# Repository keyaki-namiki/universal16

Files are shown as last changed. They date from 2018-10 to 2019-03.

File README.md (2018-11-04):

## universal16

4x4 simple Key-matrix (and some functions) with universal board

### feature(s)

- No wire is there between matrix(es) and controller footprint (for trying new controller such as Arduino, Mbed, PIC,and so on...)
- Matrix circuit is been dragged out to pads for hand-wiring
- Jumper pads for making 'hand-wiring' easier
- The universal board part for making your function (rotary encoder, potentiometer, joystick module, etc...)
- You can use universal board part in both left-side and right-side

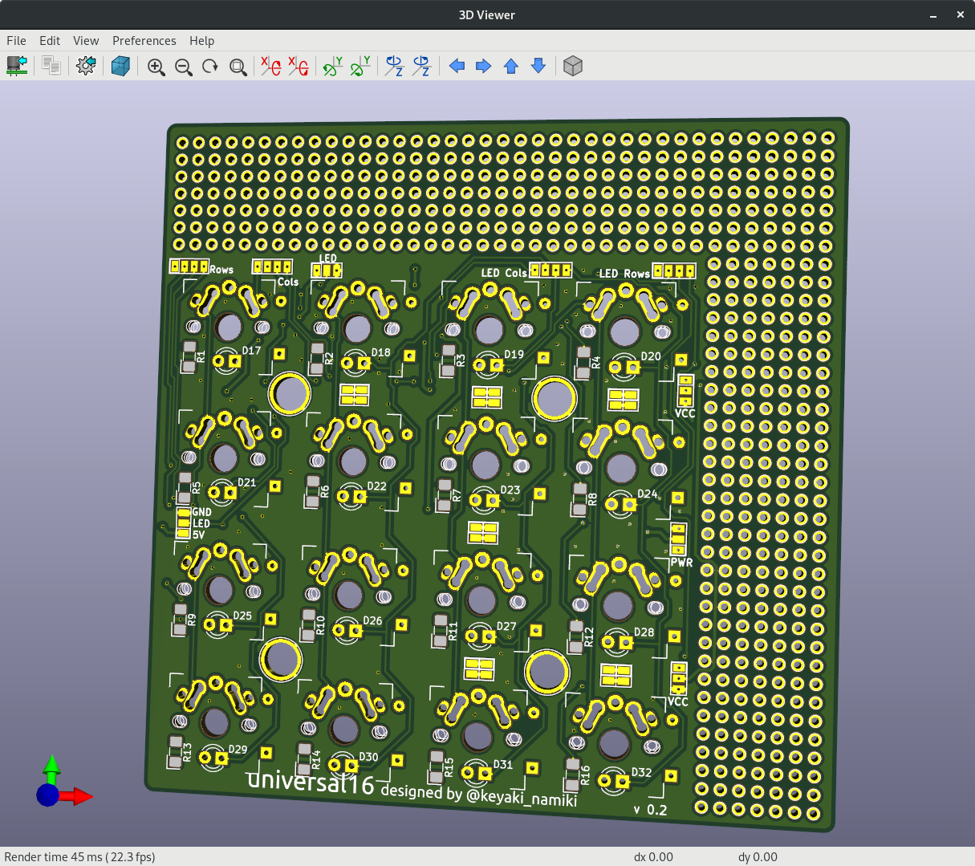
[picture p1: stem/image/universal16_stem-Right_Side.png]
universal16-stem_image_1


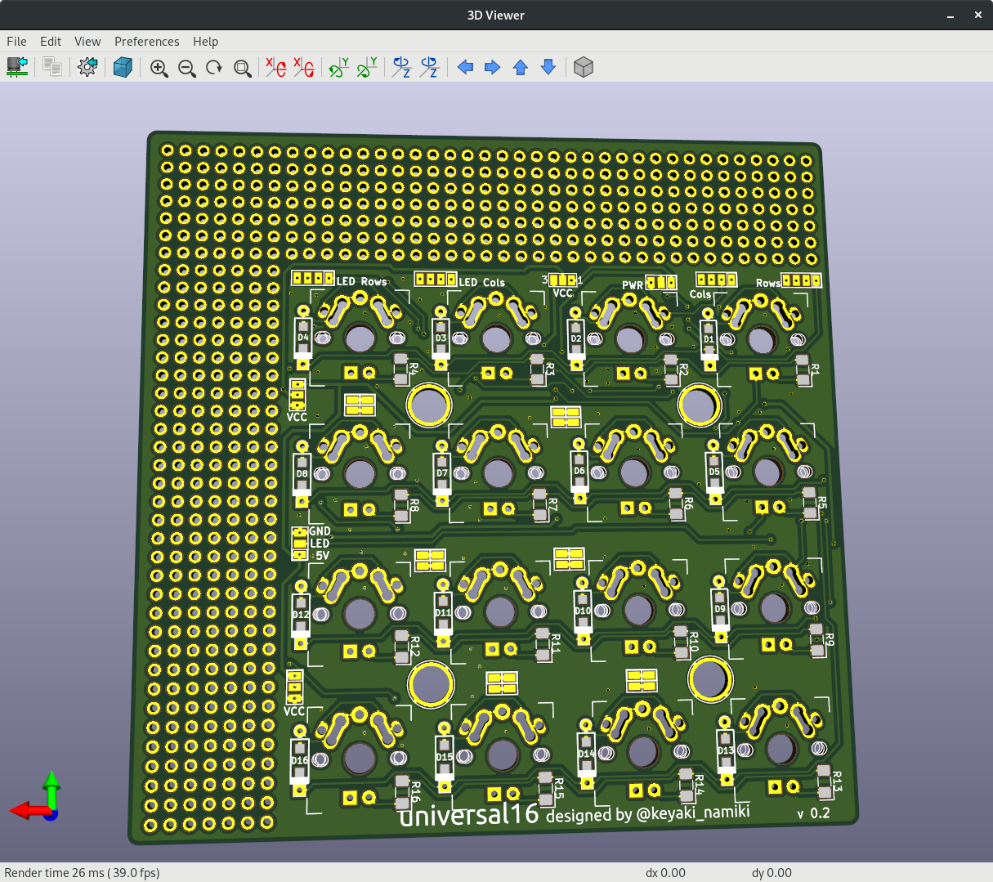
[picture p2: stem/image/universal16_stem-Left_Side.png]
universal16-stem_image_2


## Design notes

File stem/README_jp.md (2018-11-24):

## universal16 Stem

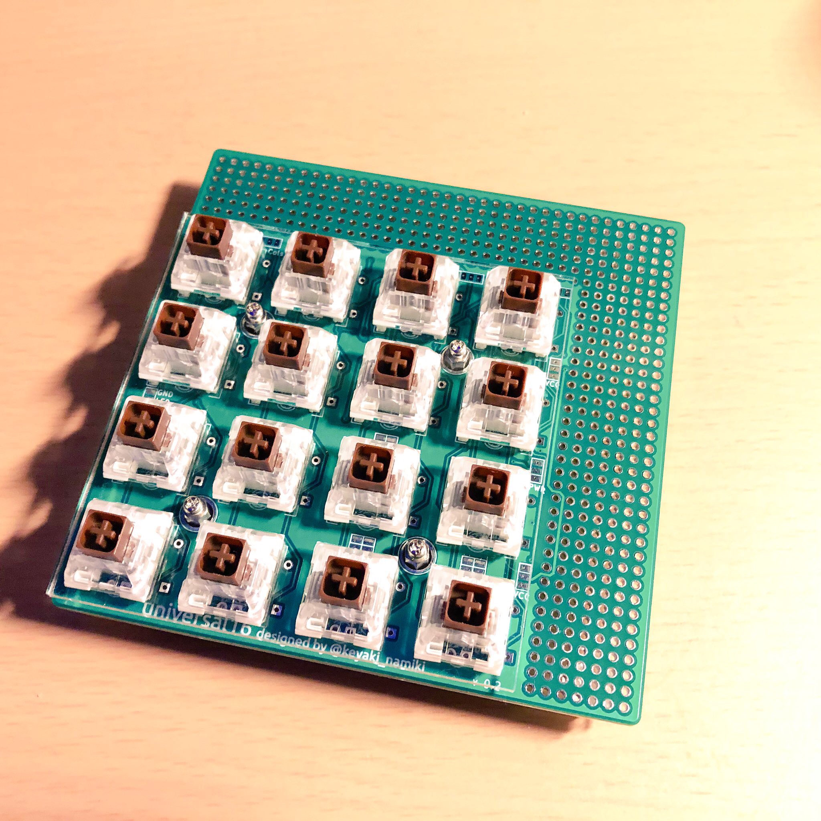
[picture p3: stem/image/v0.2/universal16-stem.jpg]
universal16-stem


universal16 Stem は4x4のキーマトリクスとユニバーサル基板を組み合わせた基板'universal16 alpha'のプレートマウント対応版です。<br>
この基板は以下の部品と合わせて使うことを想定しています。

|部品名|型番等|数量|備考|
|---|---|---|---|
|トッププレート|[acrylic/universal16](../case/acrylic/universal16.dxf)|1枚||
|ボトムプレート|[acrylic/universal16_bottom](../case/acrylic/universal16.dxf)|1枚||
|スペーサー|M2(7~8mm/4mm)|4個|ロープロファイルスイッチを使う場合、<br>4mmのスペーサーを使うことで高さを抑えることができます。|
|ネジ|M2(5~6mm/3mm)|8個||
|ダイオード|1N4148等|16個|リードタイプ推奨、表面実装も可|
|キースイッチ|Cherry MX互換品/Kailh LP|16個||
|キーキャップ|上記対応品|16個|選択したキースイッチで使用可能なキーキャップをご準備ください。|

この他に、コントローラや配線材などが必要になります。
また、バックライトLEDを使う場合は更に3mm砲弾型LEDと1206/3216サイズのチップ抵抗をそれぞれ16個ずつご準備ください。

## 配線について
universal16 Stemでは、基板の回路がパッドとして引き出してあります。どのパッドがどの配線につながっているかよく確認しながら配線してください。<br>なお、以降特に言及がない限りひとつ白枠で囲まれたものPad1として扱います。

-----
- Rows/ColsはPad1からRow/Col0-3、PWRはPad1から5V,3.3V(または任意の電圧),GND。
- ダイオード(D1-D16)を線の太い方/穴の四角い方をCathodeとして実装するとアクティブロー回路として使うことができます。

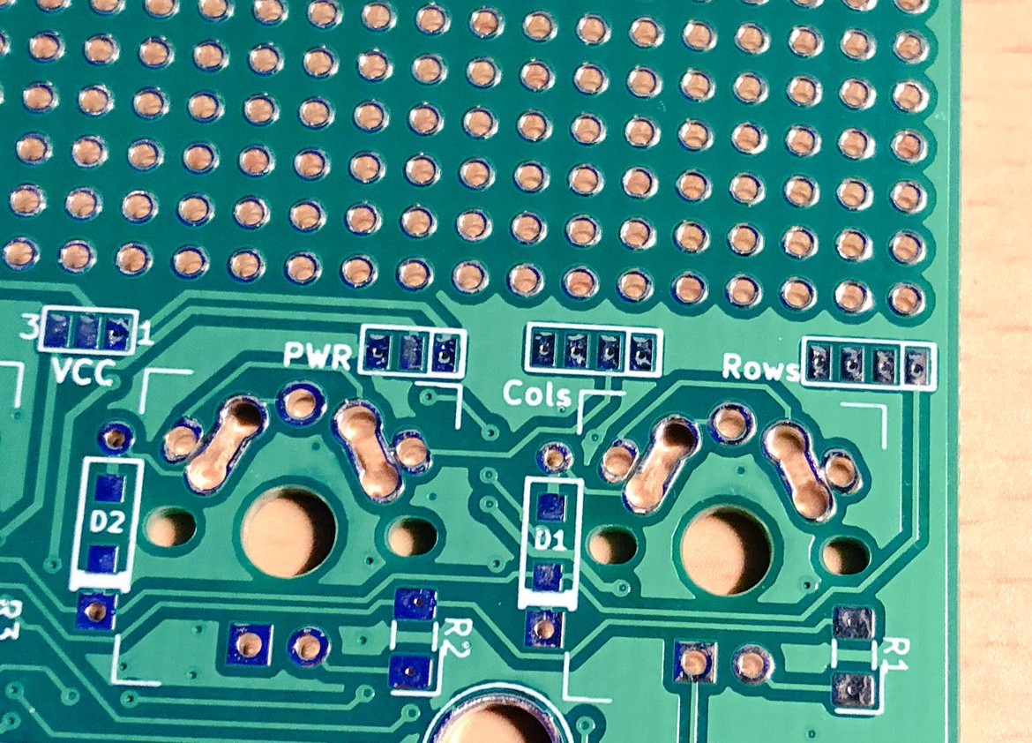
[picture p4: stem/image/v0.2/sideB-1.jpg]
universal16-stem_sideB-1


-----
- LEDRows/LEDColsはPad1からLEDRow/LEDCol0-3。<br>
  - D17-D32に'四角いスルーホール側をCathodeとしてLEDを実装した'場合、LEDRowがAnode(+)側と、LEDColがCathode(-)側とつながるように配線してあります。R1−R16に適切な値のチップ抵抗を実装してください。<br>
- VCCには2種類(後述)あるので注意してください。数字の書いていないVCCはPad1から5V,VCC,GND。

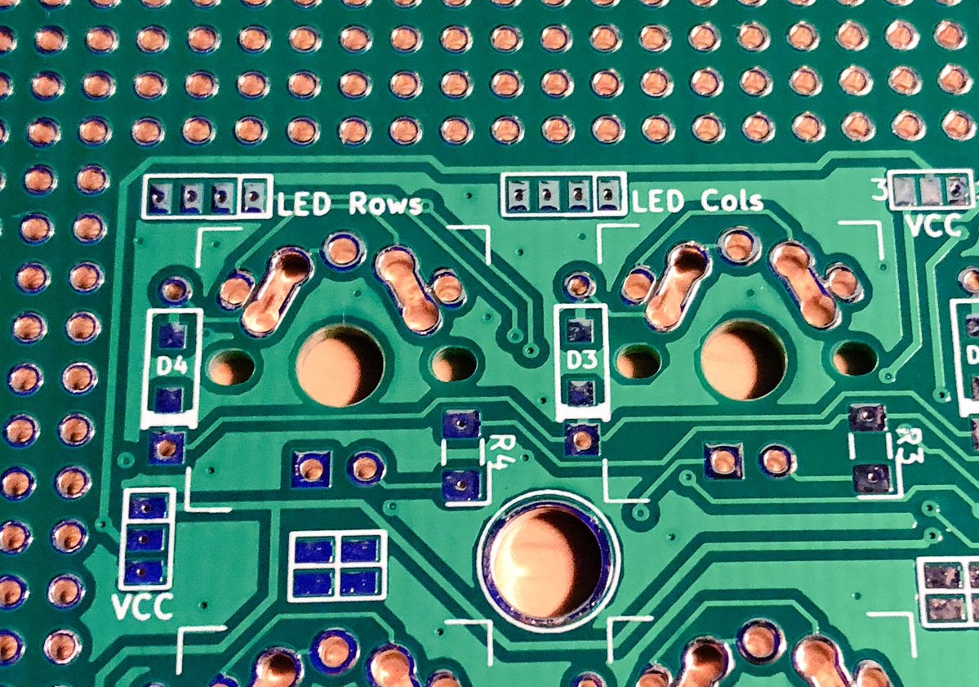
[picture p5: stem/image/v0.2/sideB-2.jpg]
universal16-stem_sideB-2


- 特にシルク印刷のない田の字型のパッドは隣り合った左右同士で以下のようにつながっています。コントローラ-ユニバーサル基板部分間を配線する際の中継地点としてご活用ください。

|1|1|
|--|--|
|2|2|

-----
- GND,LED,5Vのシルク印刷があるパッドにポリウレタン銅線などで配線することでunderglow用のLEDテープを実装できます。

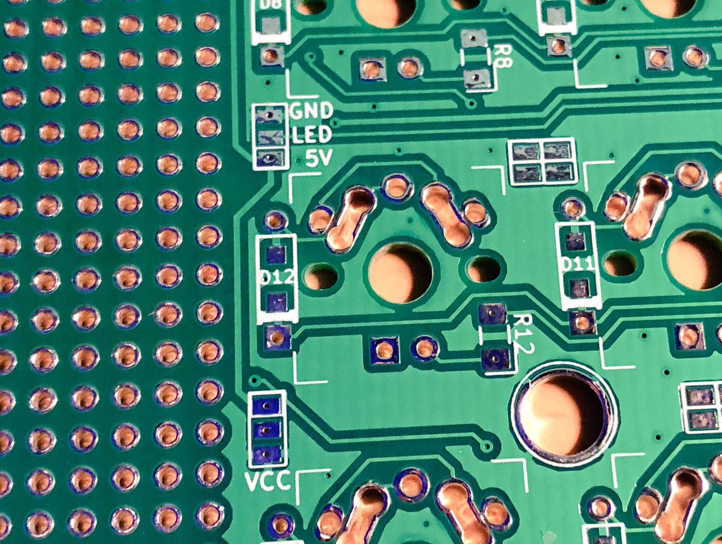
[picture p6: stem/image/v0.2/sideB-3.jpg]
universal16-stem_sideB-3


-----
- 2種類目のVCCには1と3のシルク印刷があります。1の印刷のある方から5V,VCC,3.3V(または任意の電圧)。ここを'はんだ'などで繋ぐことでさきほどのVCCに5Vまたは3.3V(または任意の電圧)を供給することができます。<br>
  - あるいはここを'はんだ'などで繋がずに'VCC'をVCCではない独立した信号線として用いることもできます。

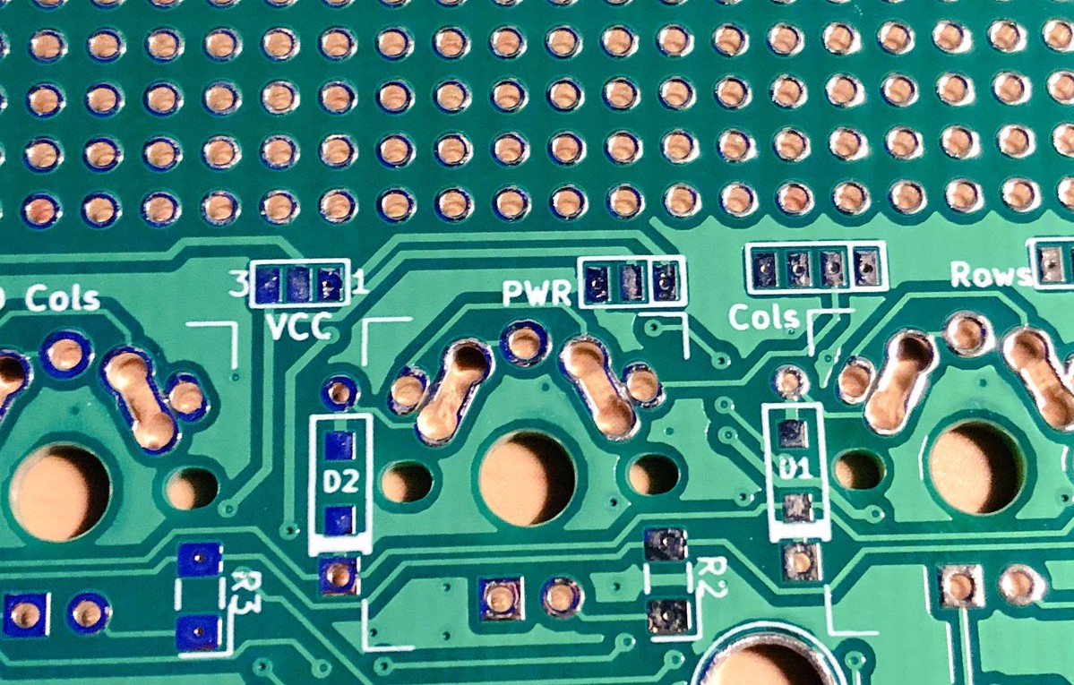
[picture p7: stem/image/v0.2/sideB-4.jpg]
universal16-stem_sideB-4


-----
- おもて面にもRows/Colsなどのパッドがあるので、ユニバーサル基板部分を左側に置いて使うこともできます。<br>
- underglow用のLED信号線はおもて面にのみ引き出してあります。Pad1から5V,LED,GND。

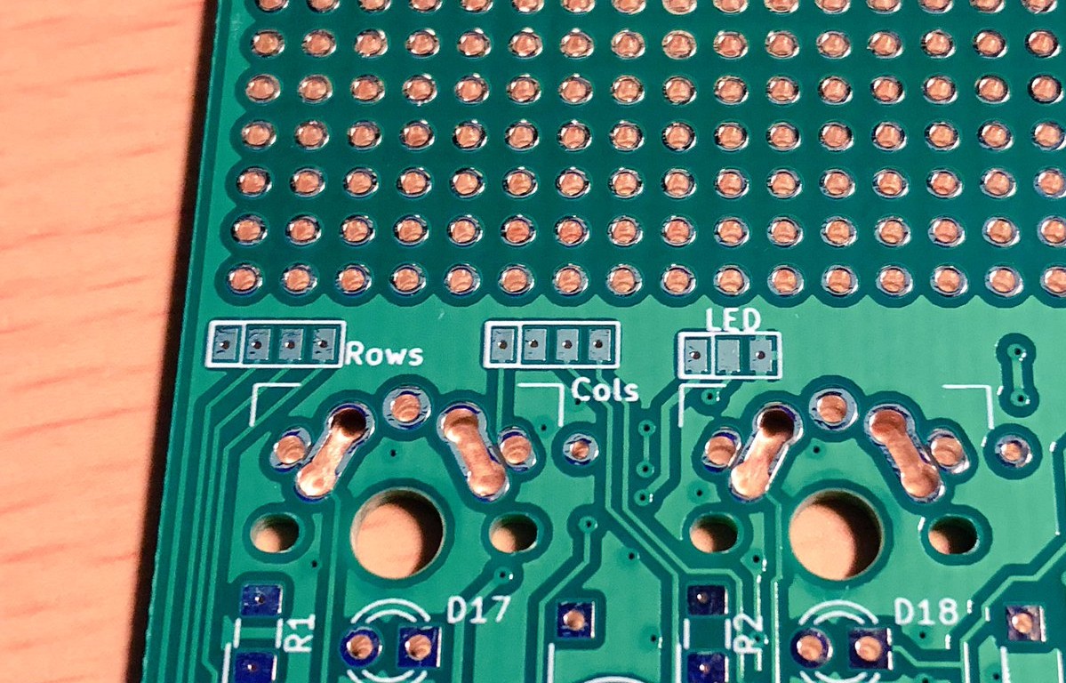
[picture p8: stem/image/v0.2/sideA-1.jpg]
universal16-stem_sideA-1


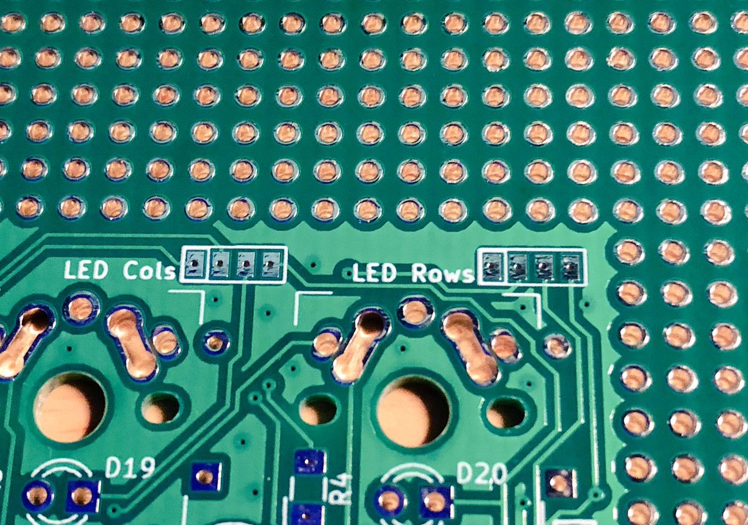
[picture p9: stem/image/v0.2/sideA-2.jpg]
universal16-stem_sideA-2


おもて面にはダイオード(D1-D16)についてシルク印刷がありませんが、キースイッチ横の2つのスルーホールは裏と表でつながっていますのでうら面と同じように実装することができます(リードタイプのみ)。

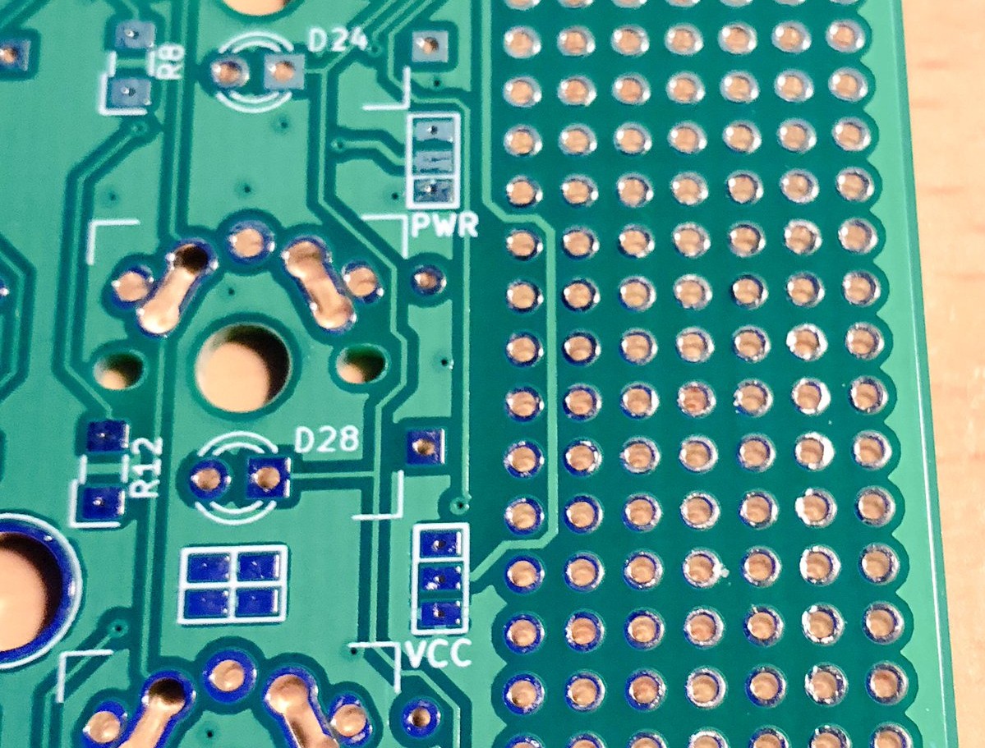
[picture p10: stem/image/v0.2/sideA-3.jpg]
universal16-stem_sideA-3


-----

qmk_firmwareを用いたビルドガイドは[こちら](https://keyaki-namiki.hatenablog.jp/entry/20181123/1542968073)

回路図のPDFは[こちら](image/v0.2/universal16-stem_schema.pdf)。

[universal16-stem_schema.pdf](image/v0.2/universal16-stem_schema.pdf)

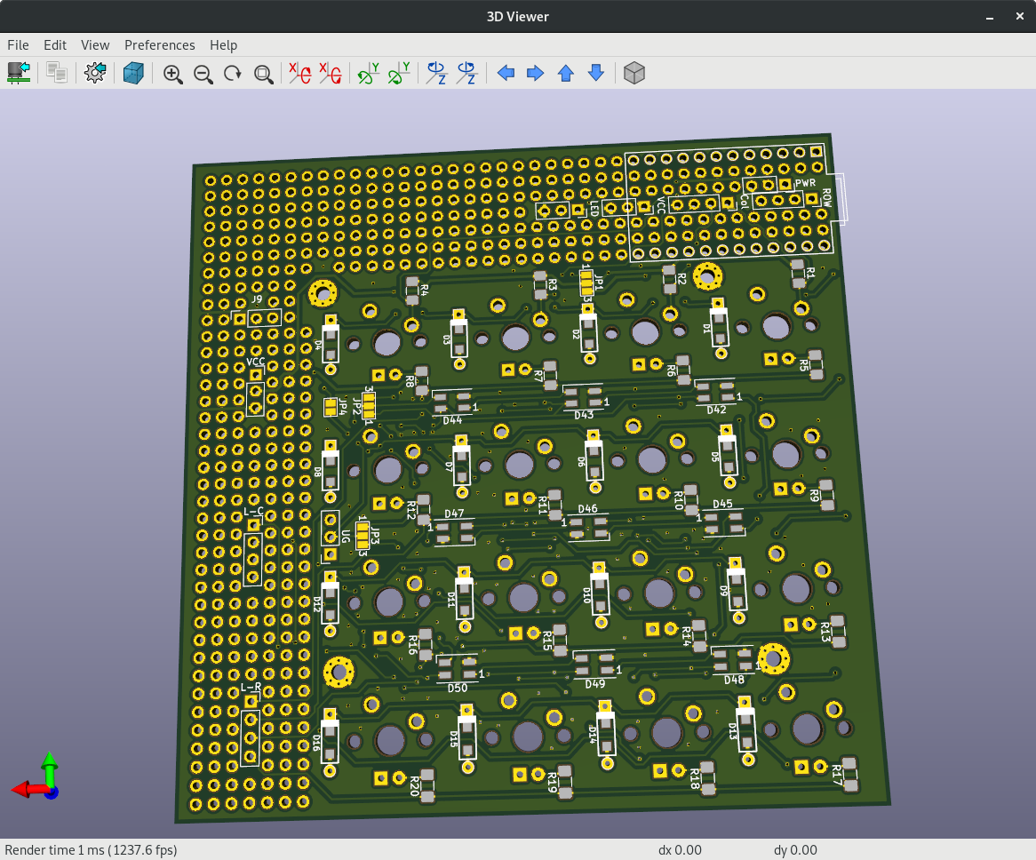
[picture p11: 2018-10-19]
alpha/image/universal16_alpha-flip.png

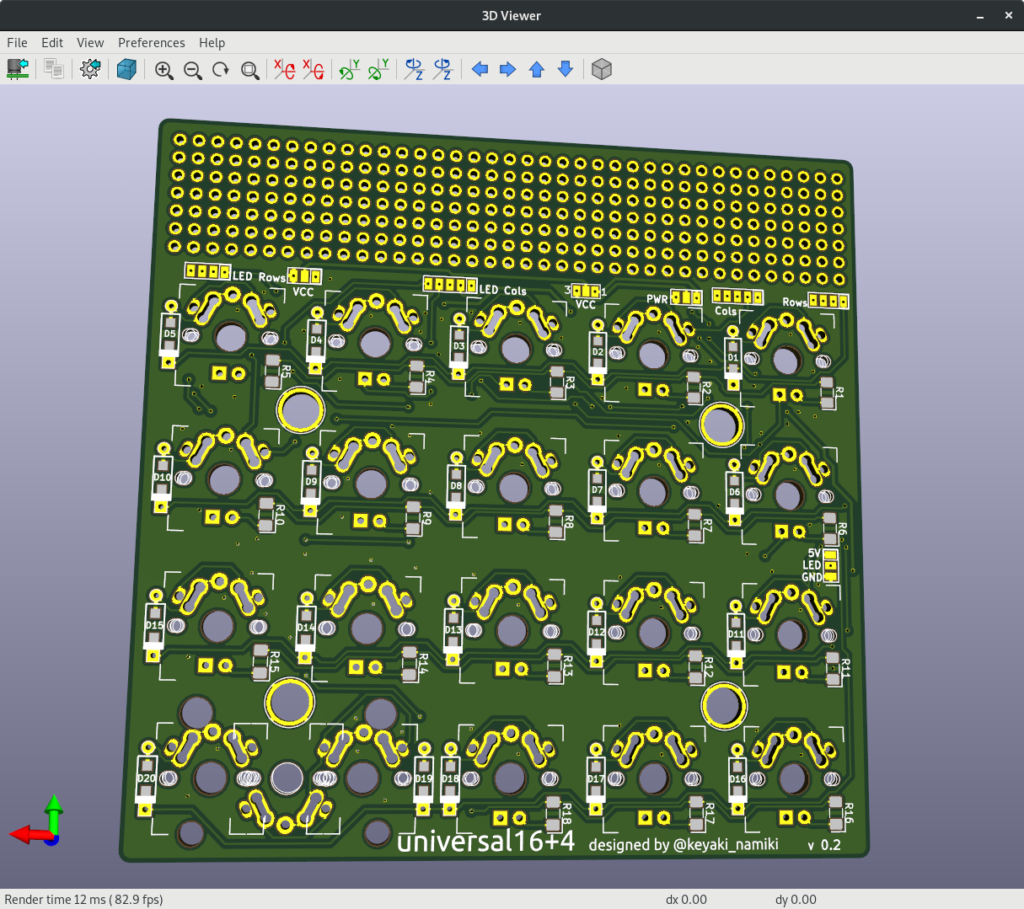
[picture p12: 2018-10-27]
plus4/image/universal16_plus4_back.png

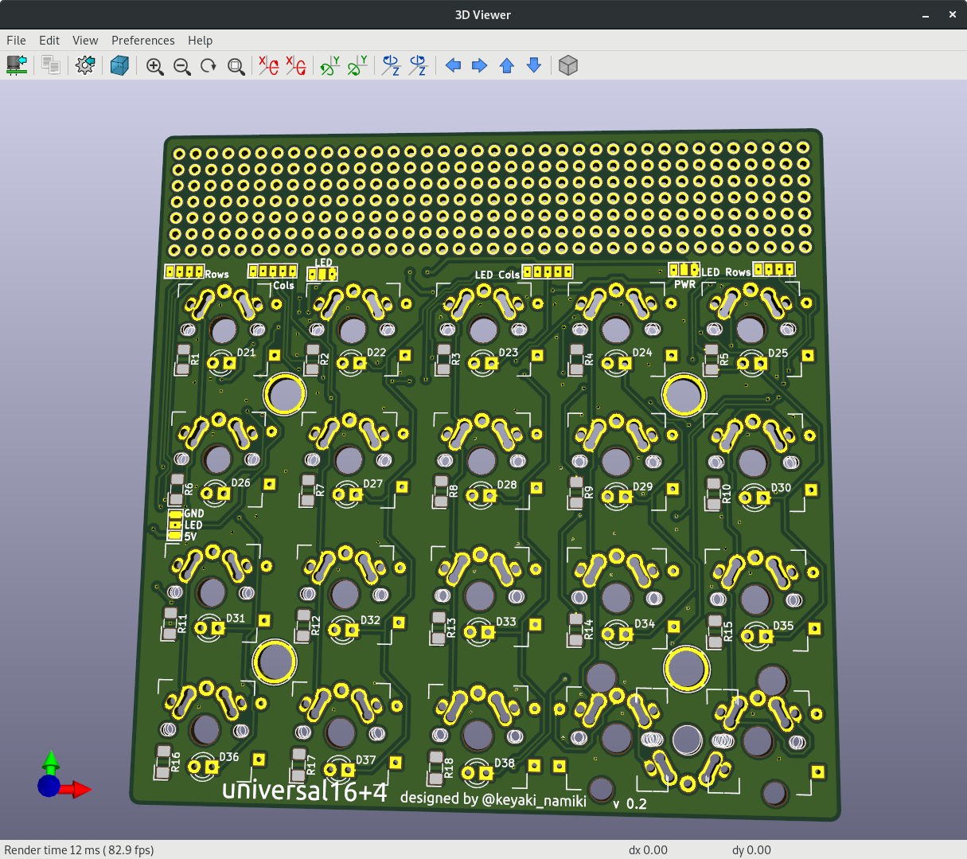
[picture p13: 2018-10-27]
plus4/image/universal16_plus4_front.png

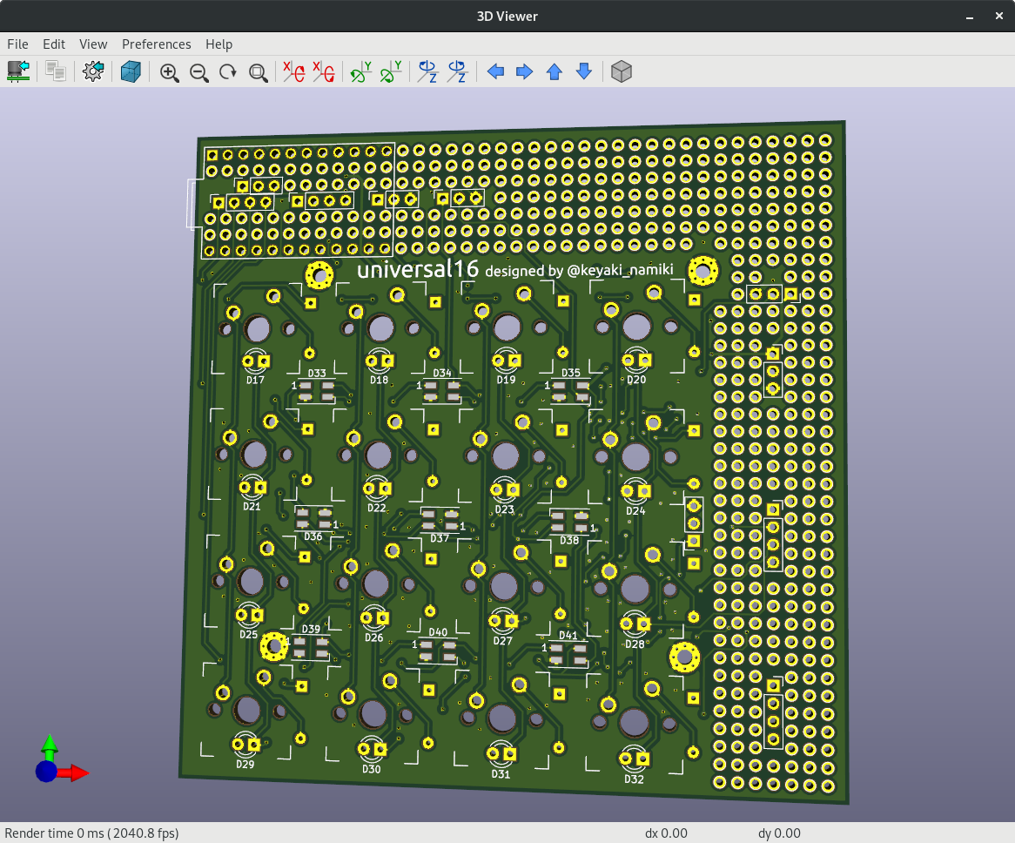
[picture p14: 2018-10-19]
alpha/image/universal16_alpha.png

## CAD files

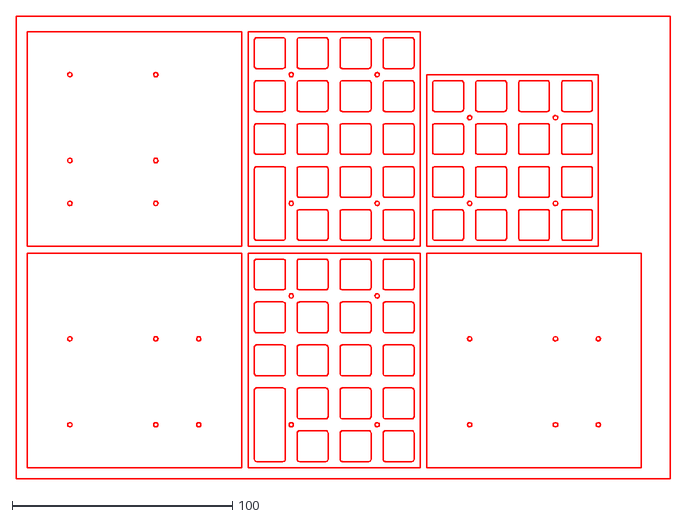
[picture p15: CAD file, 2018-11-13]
case/acrylic/universal16_case.dxf
297.0 x 210.0

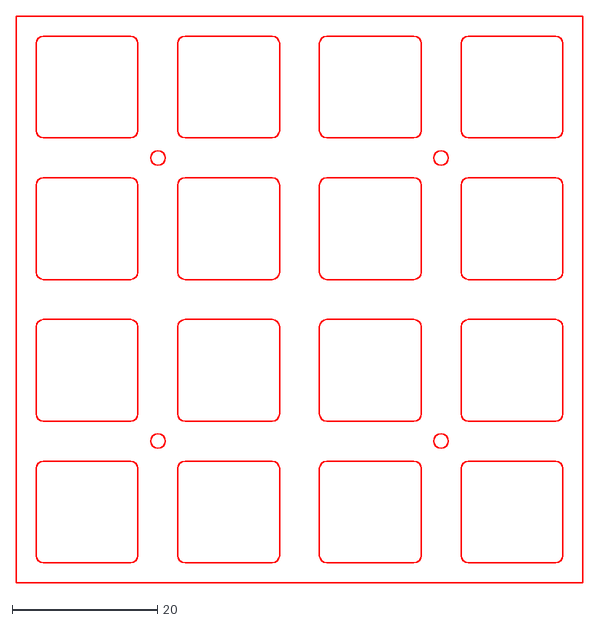
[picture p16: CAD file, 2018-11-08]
case/acrylic/universal16.dxf
78.0 x 78.0

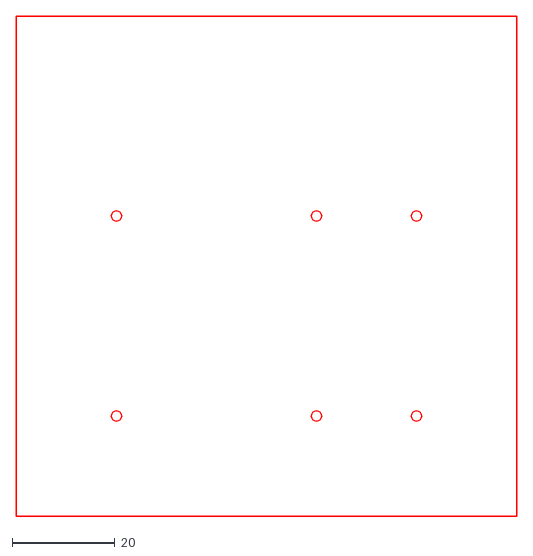
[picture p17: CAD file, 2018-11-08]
case/acrylic/universal16_bottom.dxf
97.5 x 97.5

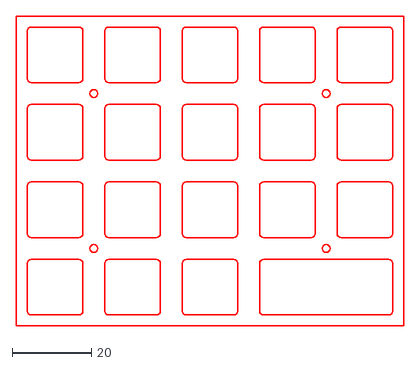
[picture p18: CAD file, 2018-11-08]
case/acrylic/universal16p4.dxf
97.5 x 78.0

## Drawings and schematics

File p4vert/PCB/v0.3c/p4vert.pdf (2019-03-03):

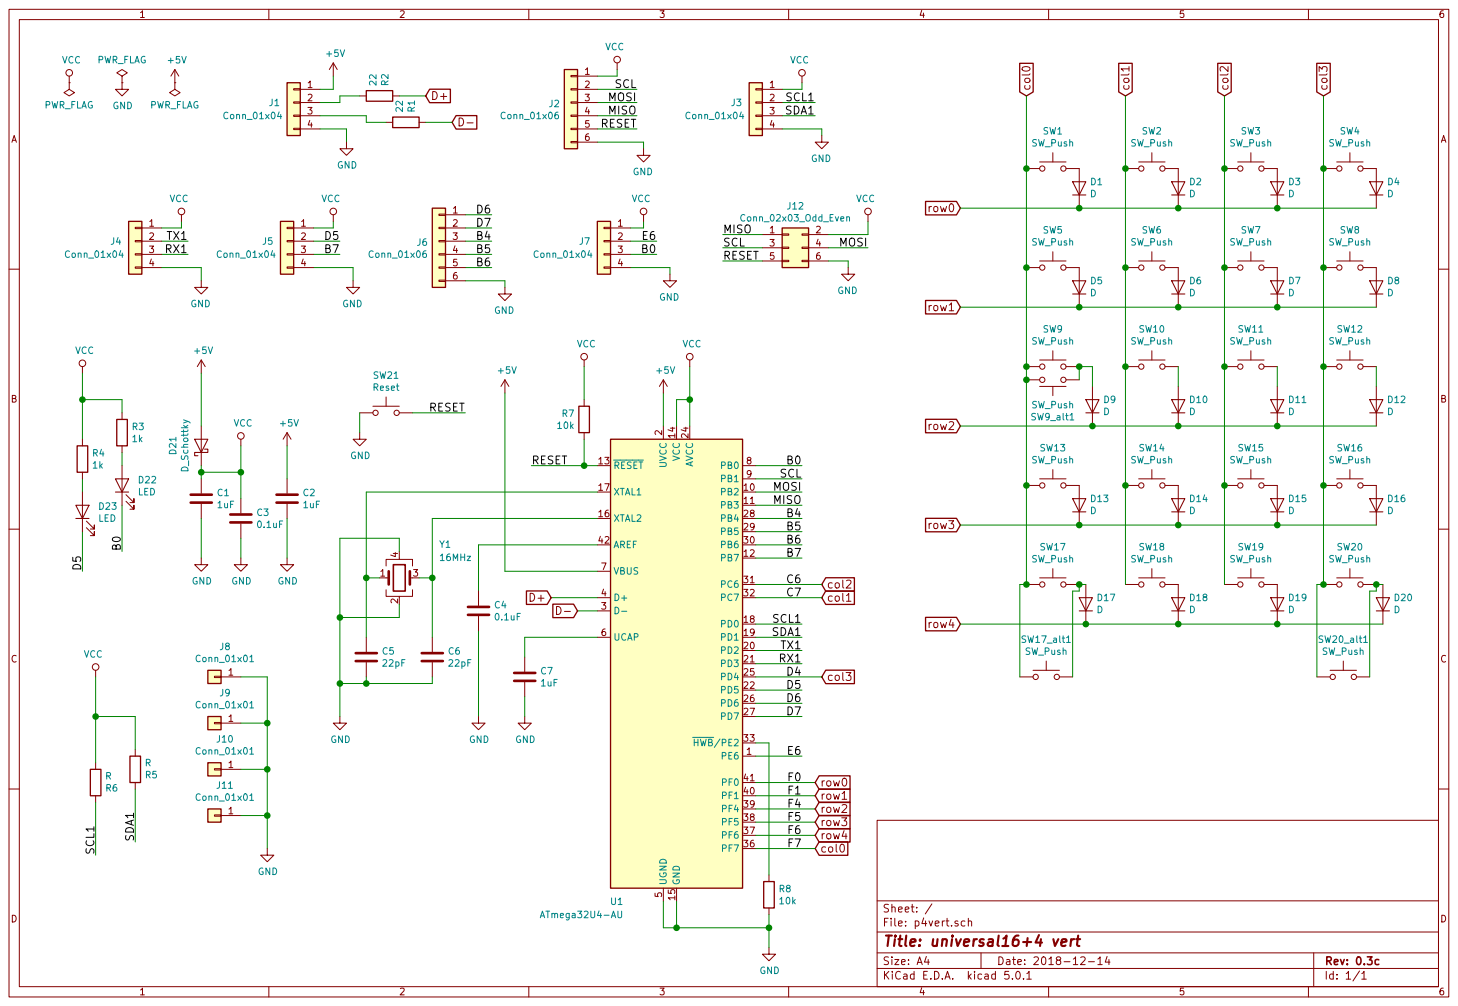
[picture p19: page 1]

2 PD2 20 PD3 21 PD5 22 AVCC 24 PD4 25 PD6 26 PD7 27 PB4 28 PB5 29 D- 3 PB6 30 PC6 31 PC7 32 HWB/PE2 33 PF7 36 PF6 37 PF5 38 PF4 39 D+ 4 PF1 40 PF0 41 AREF 42 UGND

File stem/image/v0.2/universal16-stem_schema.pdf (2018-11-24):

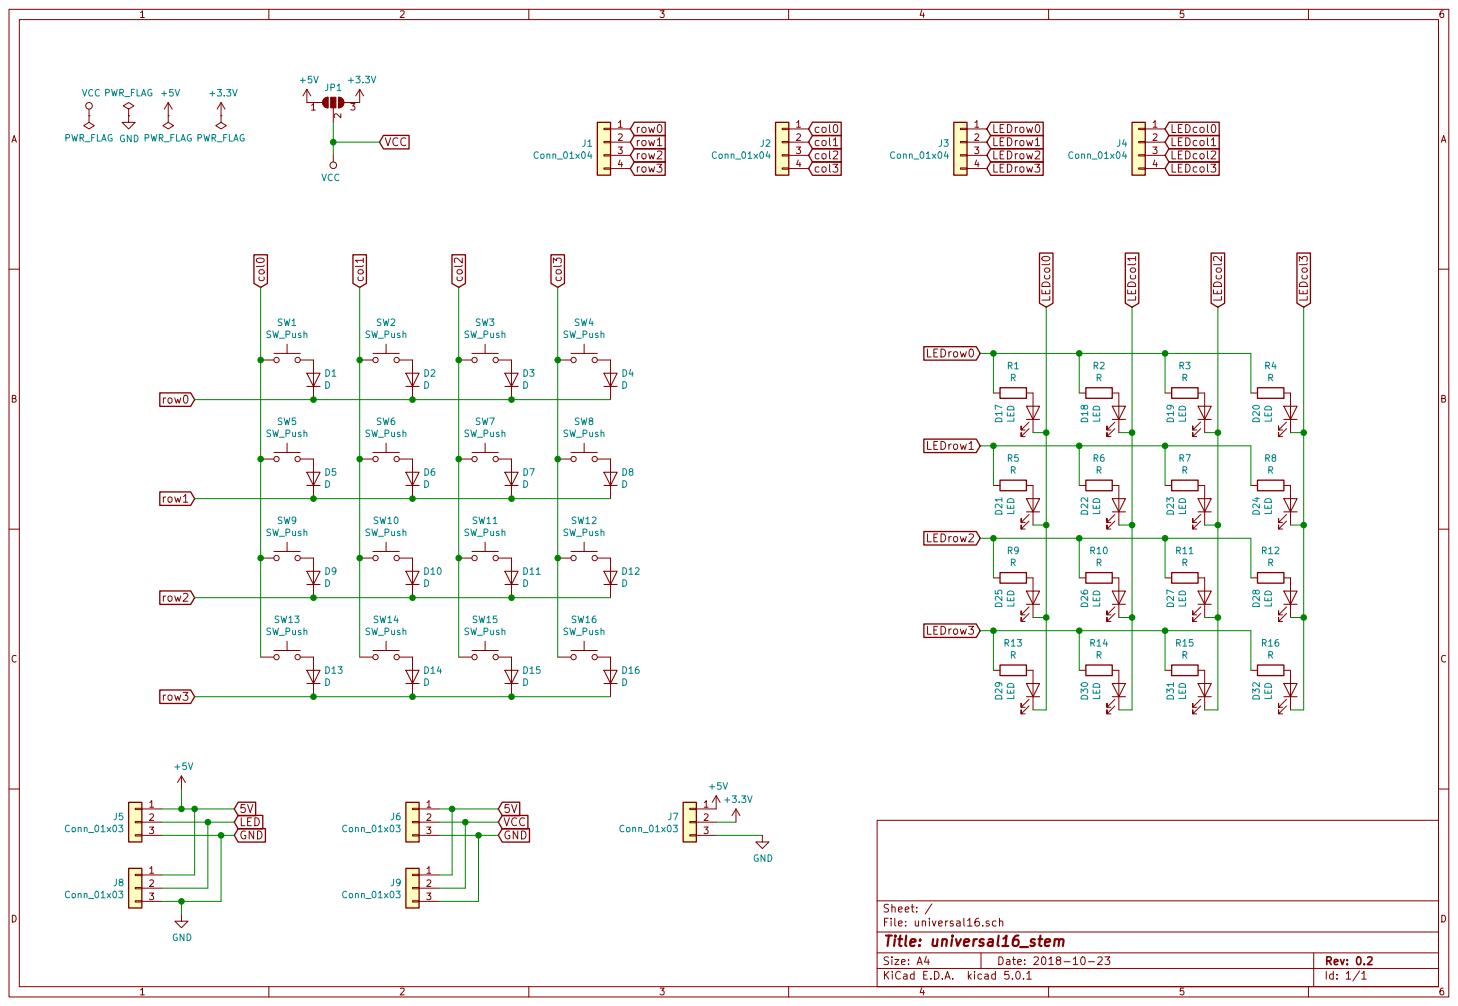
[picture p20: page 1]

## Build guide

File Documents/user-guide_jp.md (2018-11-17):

## universal16ユーザーガイド
universal16は4x4のキーマトリクスとユニバーサル基板を組み合わせたもので、新しく自作キーボードで使いたい部品やコントローラーを用いた試作/実験に便利な基板です。
このユーザーガイドではどの配線がどのパッドに引き出してあるかなどの大まかな説明をしたものです。詳しくは各PCBが置いてある階層のREADMEをご確認ください。 <br>
universal16: [universal16-stem](../stem/README_jp.md) <br>
universal16+4: [universal16plus4](../plus4/README_jp.md)

|シルク印刷|説明|
|---|---|
|Rows|キースイッチマトリクスの'行'|
|Cols|キースイッチマトリクスの'列'|
|LEDRows|LEDマトリクスの'行'|
|LEDCols|LEDマトリクスの'列'|
|LED|UnderGlow用のLED信号線|
|PWR|電源電圧2種類/GND|
|VCC|5V/VCC/GNDなど|

シルク印刷のないパッドは特に配線がなく、隣り合った2つ同士で短絡しています。コントローラ/ユニバーサル基板間の配線としてご活用ください。

## サンプルコード/プロジェクト

sample以下にArduino等で使用可能なコードを置いています。<br>
随時追加/更新してまいります。

|プロジェクト名|説明|
|---|---|
|universal16|universal16でキーマトリクスを扱うサンプルコードです。<br>キーのpress/releaseをシリアルモニタに出力します。|
|keyaki_namiki \[WIP\]|universal16を使って左手デバイスをつくるプロジェクトです。<br>master/led_ctrlの2つのプログラムでArduinoを連携させ、ロータリーエンコーダやレイヤードキーマップなどの実装を目標としています。|

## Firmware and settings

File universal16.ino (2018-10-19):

const int Rowpin[] = {4,5,7,8};
const int Colpin[] = {10,15,14,16};
const int Cols = (sizeof(Rowpin)/sizeof(Rowpin[0]));
const int Rows = (sizeof(Colpin)/sizeof(Colpin[0]));
bool beforeState[Rows][Cols];
bool currentState[Rows][Cols];
void setup(){
	Serial.begin(9600);
	while(!Serial);
	Serial.println("Started.");
	for(int i=0;i<Cols;i++){
		pinMode(Rowpin[i],OUTPUT);
	}
	Serial.print("num of Rowpin: ");
	Serial.println(Rows);
	Serial.println("Rowpin initialized.");
	for(int i=0;i<Rows;i++){
		pinMode(Colpin[i],INPUT_PULLUP);
	}
	Serial.print("num of Colpin: ");
	Serial.println(Cols);
	Serial.println("Colpin initialized.");
	for(int i=0;i<Rows;i++){
		for(int j=0;j<Cols;j++){
			currentState[i][j] = HIGH;
			beforeState[i][j] = HIGH;
		}
	}
	Serial.println("initialize finished");
}
void loop(){
	for(int i=0;i<Rows;i++){
		digitalWrite(Rowpin[i],LOW);
		for(int j=0;j<Cols;j++){
			currentState[i][j] = digitalRead(Colpin[j]);
			if (currentState[i][j] != beforeState[i][j]){
				if(currentState[i][j] == LOW){
					Serial.print("key ");
					Serial.print(i);
					Serial.print(",");
					Serial.print(j);
					Serial.println(" pressed!");
				} else {
					Serial.print("key ");
					Serial.print(i);
					Serial.print(",");
					Serial.print(j);
					Serial.println(" released!");
				}
				beforeState[i][j] = currentState[i][j];
			}
		}
		digitalWrite(Rowpin[i],HIGH);
	}
}

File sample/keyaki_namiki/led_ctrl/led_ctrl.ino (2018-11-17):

/*
 * This is a test program for universal16 with external Arduino.
 * Use with keyaki_namiki/master/master.ino
 * 
 */
#include <SoftwareSerial.h>
const int ledcols = 4;
const int ledrows = 4;
const int ledcol[ledcols] = {A2,A3,4,2};
const int srclk = 7;
const int srclr = 8;
const int sra = A0;
const int srb = A1;
//const int renc = 2;
//const int rencr[renc] = {11,6};
//const int rencg[renc] = {10,5};
//const int rencb[renc] = {9,3};

const int Tx = A4;
const int Rx = A5;
SoftwareSerial keyserial(Rx,Tx);

byte sendData,readData;

//int r[renc] = {0};
//int g[renc] = {0};
//int b[renc] = {0};
int matrixDefault[ledrows][ledcols] = {
	{1,1,1,1},
	{1,1,1,1},
	{1,1,1,1},
	{1,1,1,1}
};
int keyPressed[ledrows][ledcols]={0};
void srclock(){
	digitalWrite(srclk,1);
	digitalWrite(srclk,0);
};

void setup(){
	Serial.begin(9600);
	keyserial.begin(115200);
	while(!Serial);
	if(keyserial.available()){
	    readSerial();
	}
	pinMode(srclk,OUTPUT);
	pinMode(srclr,OUTPUT);
	pinMode(sra,OUTPUT);
	pinMode(srb,OUTPUT);
	for(int i=0;i<4;i++){
		pinMode(ledcol[i],OUTPUT);
		digitalWrite(ledcol[i],0);
	}
	Serial.println("initialized");
	digitalWrite(srclk,0);
	digitalWrite(srclr,0);
	digitalWrite(sra,0);
	digitalWrite(srb,0);
}

void loop(){
	int *matrix[ledrows];
	for(int k=0;k<ledrows;k++){
		matrix[k] = matrixDefault[k];
	}
	for(int i=0;i<ledrows;i++){
		int swapMatrix = 0;
		for(int j=0;j<ledcols;j++){
			swapMatrix += keyPressed[i][j];
		}
		if(swapMatrix != 0){
			for(int k=0;k<ledrows;k++){
				matrix[k] = keyPressed[k];
			}
			break;
		}
	}
	for(int i=ledcols;i>=0;i--){
		digitalWrite(srclr,1);
		digitalWrite(srb,1);
		for(int j=ledrows;j>=0;j--){
			digitalWrite(sra,matrix[j][i]);
			srclock();
			digitalWrite(sra,0);
		}
		digitalWrite(ledcol[i],1);
		delay(3);
		digitalWrite(srclr,0);
		digitalWrite(ledcol[i],0);
	}
	if(keyserial.available()){
		readSerial();
	}
}

void readSerial(){
	int Row1, Col1, isPress;

	readData = keyserial.read();
	Serial.println(readData);

	if(readData & 0b00000000){

	} else {
		isPress = readData >> 5;
		Row1 = (readData & 0b00011000) >> 3;
		Col1 = (readData & 0b00000110) >> 1;
		Serial.print("key ");
		Serial.print(Row1);
		Serial.print(",");
		Serial.print(Col1);
		if(isPress){
			keyPressed[Row1][Col1] = 1;
			Serial.println(" pressed!");
		} else {
			keyPressed[Row1][Col1] = 0;
			Serial.println(" released!");
		}
	}
}

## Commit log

2018-10-06 rename some files
    [universal16.kicad_pcb, universal16.sch]
2018-10-19 update some footprints
    [universal16.kicad_pcb, universal16.sch]
2018-10-19 sample program for arduino
2018-10-26 rename some old files
    [universal16.kicad_pcb, universal16.sch]
2018-10-26 new pcb design
    ~new feature~
    -some holes for plate mounting stem
    -some pads for 'hand-wiring'
    -new footprint for kailh LP switches
    -new footprint for flipping PCB
    [universal16.kicad_pcb, universal16.sch]
2018-10-27 redraw some wires
    [universal16.kicad_pcb]
2018-10-27 fix footprint compatibility
    [universal16.kicad_pcb]
2018-10-27 new PCB design
    [universal16p4.kicad_pcb, universal16p4.sch]
2018-10-30 rename sample code's path
2018-11-08 add some acrylic case designs
    [universal16.dxf, universal16_bottom.dxf, universal16_case.dxf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]
2018-11-13 aligned some parts
    [universal16_case.dxf]
2018-11-17 add sample code by 'keyaki_namiki'
2018-11-24 update some documentations
    [universal16.sch]
2019-01-08 add new pcb design
    -universal16+4 in numpad style
    -all pins of ATmega32u4 are dragged out to each pad
    [p4vert.kicad_pcb, p4vert.sch]
2019-03-03 minor fixes
    [p4vert.kicad_pcb, p4vert.sch]
2019-03-03 add new pcb design
    [p4vert.kicad_pcb, p4vert.sch]
2019-03-03 add new case designs/materials
    [p4vert_bottom.kicad_pcb, p4vert_bottom.sch, p4vert_top.kicad_pcb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]
2019-03-03 add schema file in pdf style
    [p4vert.sch]
